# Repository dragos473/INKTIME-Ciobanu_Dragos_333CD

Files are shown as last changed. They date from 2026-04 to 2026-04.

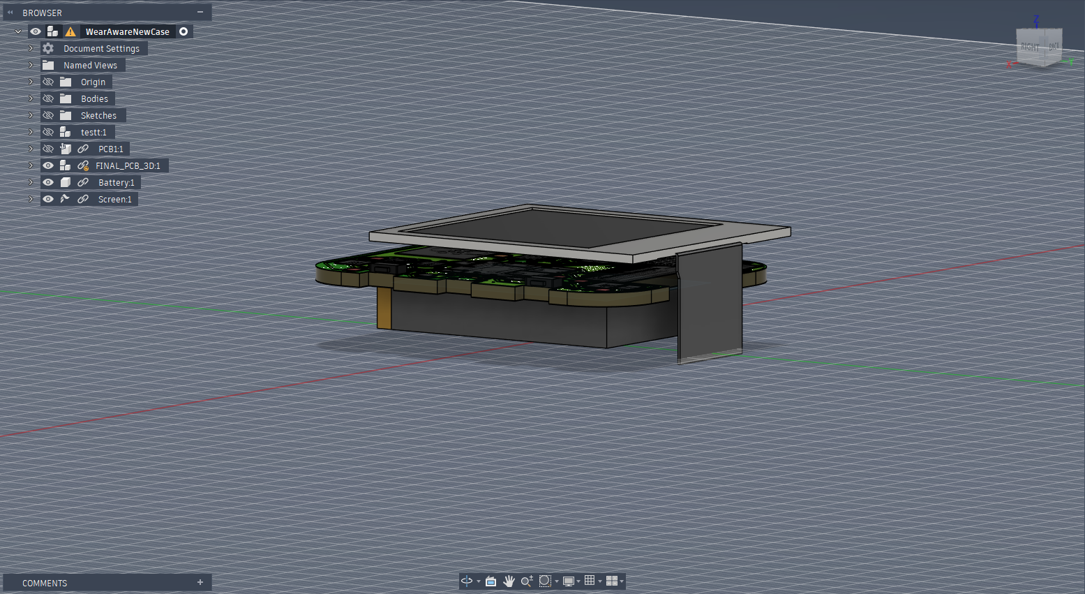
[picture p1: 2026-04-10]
Images/3Dmodel-noCase.PNG

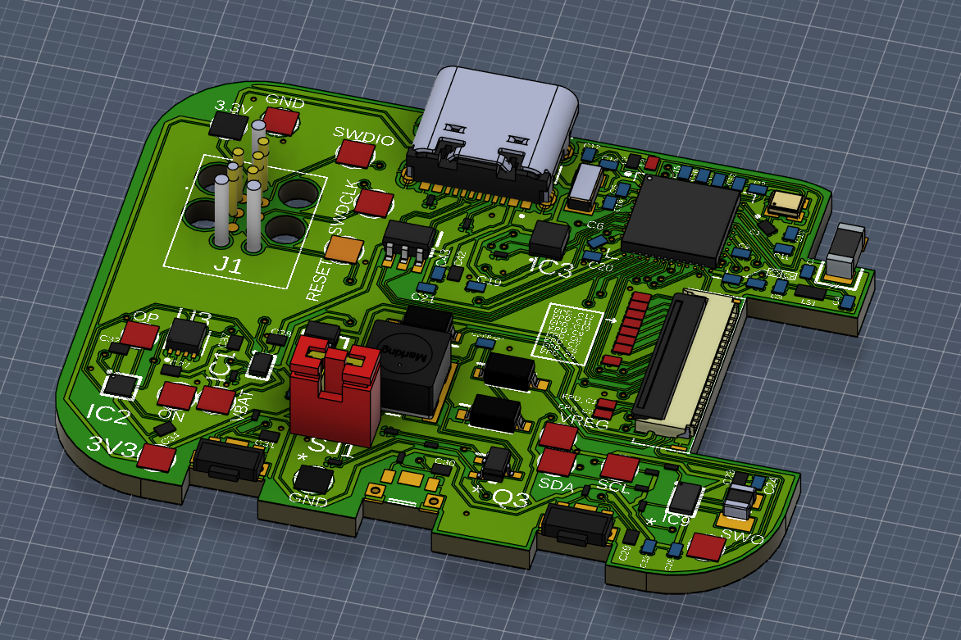
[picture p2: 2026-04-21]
Images/3DPCBTop.PNG

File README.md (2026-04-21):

# InkTime – Smartwatch Open Source

InkTime este un smartwatch open-source construit in jurul microcontroller-ului nRF52840. Are display e-paper de 1.54", feedback haptic, si incarcare prin USB-C.

## Diagrama Bloc

```
                         +-----------+
        USB-C ──VBUS──>──| BQ25180   |──VBAT──>──[ Baterie LiPo ]
        (J3)             | (Charger) |              |
          |              +-----------+               |
          |                   |                      |
          |                   v                      v
          |              +-----------+         +-----------+
          |              | RT6160A   |<──VREG──| MAX17048  |
          |              | (DC/DC)   |         | (Fuel     |
          |              +-----------+         |  Gauge)   |
          |                   |                +-----------+
          |                 3V3                      |
          |                   |                   ALERT
          v                   v                      |
     +--------------------------------------------+  |
     |               nRF52840                      |<-+
     |                                             |
     |   SPI ──> Display E-Paper (conector FPC J2) |
     |   I2C ──> BMA423 (IMU)                      |
     |   I2C ──> DRV2605 (Haptic Driver)           |
     |   I2C ──> BQ25180 / RT6160A / MAX17048      |
     |   GPIO ──> 3x Butoane (UP/ENTER/DOWN)       |
     |   USB ──> USB-C (D+/D-)                     |
     |   RF ──> Antena 2.4GHz (BLE)                |
     +---------------------------------------------+
```

## Descriere Hardware

### Microcontroller – nRF52840

nRF52840 e IC-ul principal al proiectului. E un SoC cu procesor Cortex-M4F, are 1MB flash si 256kB RAM si merge pana la 64MHz. Suporta BLE 5.0 si USB 2.0. Toate perifericele de pe placa comunica cu el prin I2C, SPI sau GPIO.

### Alimentare

Lantul de alimentare arata asa: USB-C (VBUS, 5V) → BQ25180 (incarcator LiPo) → baterie LiPo (VBAT) → RT6160A (convertor DC/DC buck-boost) → linia de 3V3.

### Display E-Paper

Display-ul se conecteaza printr-un conector FPC cu 24 de pini. Circuitul de drive pentru e-paper foloseste un boost converter ca sa genereze tensiunile mari (PREVGH si PREVGL) de care are nevoie panoul. Un P-MOSFET (DMG2305UX) controlat de pinul P1.01 porneste/opreste alimentarea circutului de display, ca sa poata fi oprit complet cand nu se face refresh.

Semnalele SPI (SCK, MOSI, CS) si GPIO-urile de control (DC, RST, BUSY) merg direct la nRF52840. Fiecare linie de tensiune mare are condensatoare de decuplare de 1µF/50V.

### IMU – BMA423

BMA423 e un accelerometru triaxial folosit pentru numararea pasilor si detectarea gesturilor. Comunica pe I2C. Pinul SDO e legat la GND printr-un rezistor de 0Ω (R3), ceea ce seteaza adresa I2C la 0x18. CSB e legat la VDD ca sa selecteze modul I2C. INT1 si INT2 merg la nRF52840 pentru interrupt-uri.

### Haptic Driver – DRV2605

DRV2605 controleaza un motor LRA/ERM pentru feedback haptic. E controlat prin I2C si activat prin GPIO (P0.12 → EN). Pinul IN/TRIG e legat la GND (nu se foloseste in modul I2C). OUT+ si OUT- se conecteaza la motor prin test pad-uri.

### USB-C si Protectie ESD

Conectorul USB-C (KH-TYPE-C-16P) furnizeaza alimentare (VBUS) si date (D+, D-). Doua rezistoare de 5.1kΩ pe CC1 si CC2 identifica dispozitivul ca UFP (sink). USBLC6-2SC6Y asigura protectie ESD pe liniile de date. D+/D- se conecteaza la controller-ul USB intern al nRF52840.

### Butoane

Trei butoane tactile (EVP-AKE31A): UP (P0.13), ENTER (P0.14), DOWN (P1.02). Fiecare buton are un pull-up de 10kΩ la 3V3 si un condensator de debounce de 1µF la GND. Cand e apasat, butonul trage pinul la GND (active-low).

### Debug SWD

Un footprint TC2030-IDC (tag-connect) ofera acces SWD (SWDIO, SWDCLK, RESET, VCC, GND). Pe placa sunt si test pad-uri pentru SWO, SWDIO, SWDCLK, RESET, 3V3 si GND.

### Magistrala I2C

Toate perifericele I2C sunt pe acelasi bus, pe pinii P0.06 (SDA) si P0.07 (SCL). Rezistoarele de pull-up sunt de 3.3kΩ, conectate la 3V3.

| Dispozitiv | Adresa I2C | Functie |
|---|---|---|
| BQ25180 | 0x6A | Incarcator baterie |
| RT6160A | 0x75 | Convertor DC/DC |
| MAX17048 | 0x36 | Fuel gauge |
| BMA423 | 0x18 | Accelerometru |
| DRV2605 | 0x5A | Driver haptic |

## Pinii nRF52840

| Pin | Pad | Semnal | Descriere |
|-----|-----|---|---|
| P0.00 | D2 | XL1 | Intrare cristal 32.768kHz |
| P0.01 | F2 | XL2 | Iesire cristal 32.768kHz |
| P0.02 | A12 | SCK | SPI clock catre display e-paper |
| P0.03 | B13 | MOSI | SPI data catre display e-paper |
| P0.05 | K2 | EPD_CS | SPI chip select pentru display |
| P0.06 | L1 | SDA | I2C data (bus comun) |
| P0.07 | M2 | SCL | I2C clock (bus comun) |
| P0.08 | N1 | IMU_INT1 | Interrupt 1 de la BMA423 |
| P0.10 | J24 | ALERT | Alerta baterie de la MAX17048 |
| P0.11 | T2 | PMIC_INT | Interrupt de la BQ25180 |
| P0.12 | U1 | HAPTIC_EN | Enable pentru DRV2605 |
| P0.13 | AD8 | BTN_UP | Buton UP (active-low) |
| P0.14 | AC9 | BTN_ENTER | Buton ENTER (active-low) |
| P0.15 | AD10 | EPD_DC | Data/Command pentru display |
| P0.16 | AC11 | EPD_RST | Reset display e-paper |
| P0.17 | AD12 | EPD_BUSY | Busy flag display e-paper |
| P0.18 | AC13 | RESET | Reset sistem |
| P1.00 | AD22 | SWO | Serial Wire Output (debug) |
| P1.01 | Y23 | PWR_EPD | Gate MOSFET alimentare display |
| P1.02 | W24 | BTN_DOWN | Buton DOWN (active-low) |
| P1.08 | P2 | IMU_INT2 | Interrupt 2 de la BMA423 |
| AD2 | — | VBUS | Detectie USB VBUS |
| AD4 | — | D- | USB data minus |
| AD6 | — | D+ | USB data plus |
| AA24 | — | SWDCLK | SWD clock (debug) |
| AC24 | — | SWDIO | SWD data (debug) |
| XC1/B24 | — | XC1 | Intrare cristal 32MHz |
| XC2/A23 | — | XC2 | Iesire cristal 32MHz |
| H23 | — | ANT | Iesire RF catre antena |
| W1, B1, A22, AD14, AD23 | — | VDD | Alimentare 3.3V |
| Y2 | — | VDDH | Alimentare 3.3V (high-voltage) |
| B7, F23 | — | VSS/GND | Masa |

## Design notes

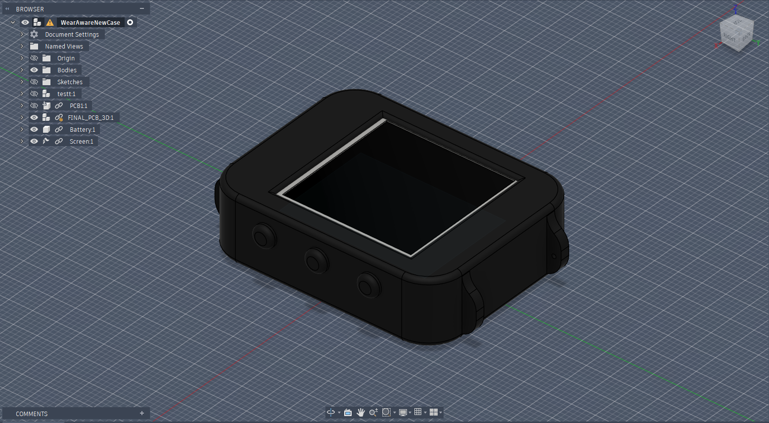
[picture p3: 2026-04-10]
Images/3Dmodel-withCase.PNG

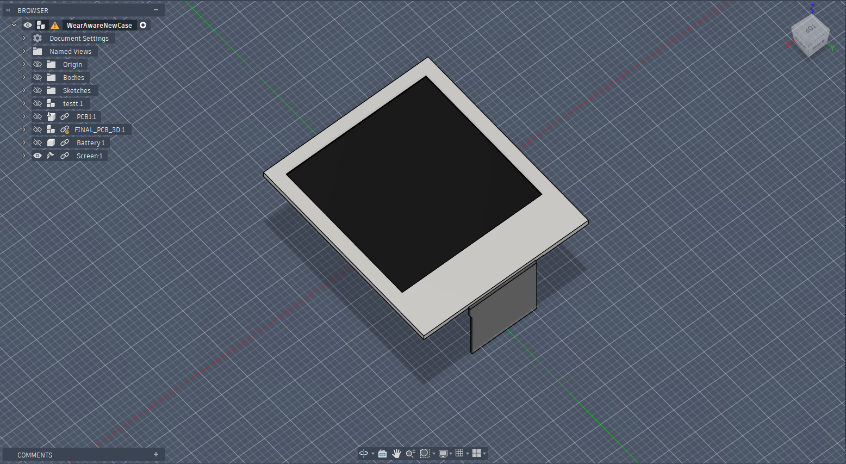
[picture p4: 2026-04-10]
Images/3DScreen.PNG

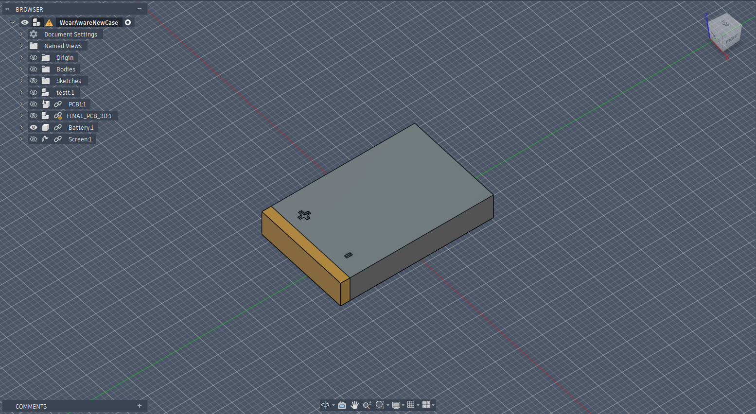
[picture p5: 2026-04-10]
Images/3DBattery.PNG

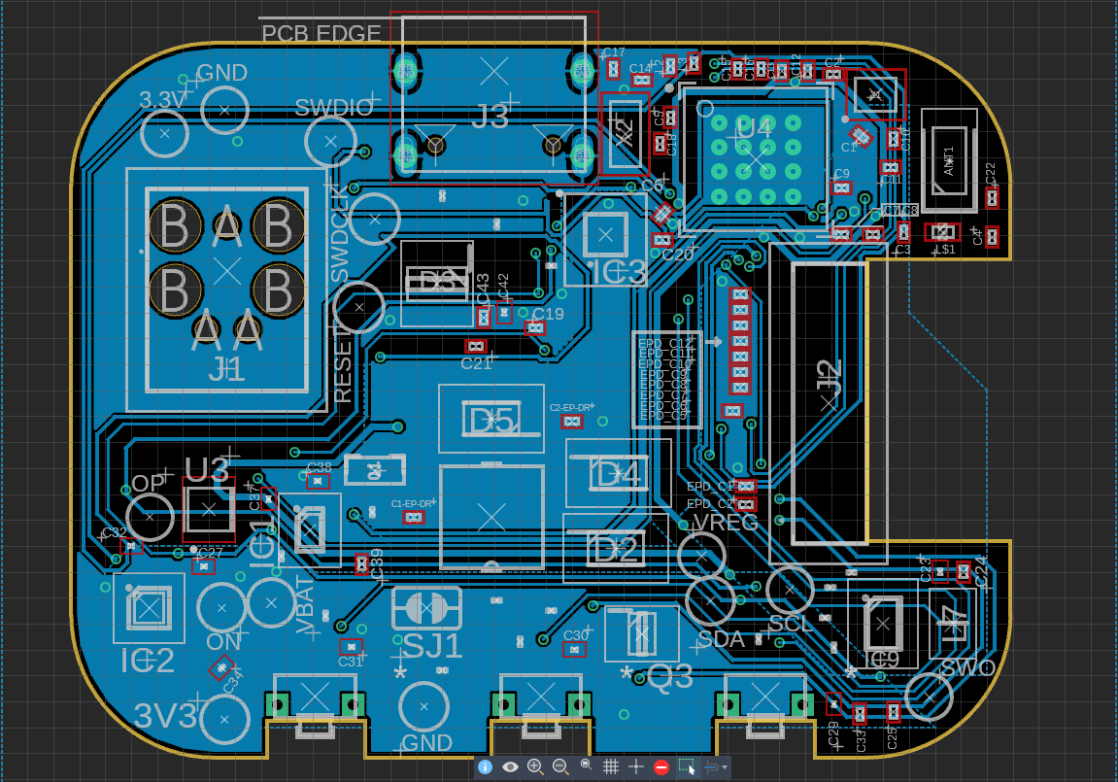
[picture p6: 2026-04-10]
Images/PCBBottom.PNG

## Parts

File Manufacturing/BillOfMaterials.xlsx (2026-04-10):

Reference Designators | Quantity | Description | Datasheet | Purchase Link | Package | Value | Manufacturer | Manufacturer Part Number | Vendor | Vendor Part Number | Top/Bottom
 | 1 | PCB Board |  |  | Board
3.3V, 3V3, GND, ON, OP, RESET, SCL, SDA, SWDCLK, SWDIO, SWO, TP_BAT_GND, VBAT, VREG | 14 | Test pad |  |  | HECTOR_WATCH_1_TP20R | HECTOR_WATCH_1_TPTP20R |  |  |  |  | Top
ANT1 | 1 | Antennas 2.45GHz ANTENNA | READ_DATASHEET | BUY_PART | 2450AT18B100E_ANTC3216X140N | 2450AT18B100E | Johanson Technology | 2450AT18B100E | LCSC | C2836414 | Top
C1, C2, C17, C18 | 4 | Generic chip capacitor | READ_DATASHEET | BUY_PART | NORDIC_NRF_3_RESC0201_L | 12pF | Murata | GRM0335C1H120JA01D | LCSC | C106295 | Top
C1-EP-DR, C24, C39 | 3 | Generic chip capacitor | READ_DATASHEET |  | NORDIC_NRF_3_RESC0201_L | 10uF | Murata | GRM155R60J106ME15 |  |  | Top
C2-EP-DR, C43 | 2 | Generic chip capacitor |  |  | NORDIC_NRF_3_RESC0201_L | 4.7uF |  |  |  |  | Top
C3, C4 | 2 | Generic chip capacitor |  |  | NORDIC_NRF_3_RESC0201_L | 1pF |  |  |  |  | Top
C5, C7, C12, C19 | 4 | Generic chip capacitor |  |  | NORDIC_NRF_3_RESC0201_L | 100nF | Murata | GRM033R60J104KE19D |  |  | Top
C6, C14, C20, C21 | 4 | Generic chip capacitor |  |  | NORDIC_NRF_3_RESC0201_L | 4.7μF |  |  |  |  | Top
C8 | 1 | Generic chip capacitor |  |  | NORDIC_NRF_3_RESC0201_L | 100nF N.C. |  |  |  |  | Top
C9 | 1 | Generic chip capacitor |  |  | NORDIC_NRF_3_RESC0201_L | 820pF |  |  |  |  | Top
C10, C13, C22 | 3 | Generic chip capacitor |  |  | NORDIC_NRF_3_RESC0201_L | N.C. |  |  |  |  | Top
C11 | 1 | Generic chip capacitor |  |  | NORDIC_NRF_3_RESC0201_L | 100pF |  |  |  |  | Top
C15 | 1 | Generic chip capacitor |  |  | NORDIC_NRF_3_RESC0201_L | 1.0μF |  |  |  |  | Top
C16 | 1 | Generic chip capacitor |  |  | NORDIC_NRF_3_RESC0201_L | 47nF |  |  |  |  | Top
C23, C27, C34, C42 | 4 | Check availability |  |  | CAPC0201X13N | 0.1uF |  |  |  |  | Top
C25, C33 | 2 | Generic chip capacitor |  |  | NORDIC_NRF_3_RESC0201_L | 22uF | Murata | GRM188R61A226ME15D |  |  | Top
C29, C30, C31, C32, C37, C38 | 6 | Check availability |  |  | CAPC0201X13N | 1uF |  |  |  |  | Top
D2, D4, D5 | 3 | ON SEMICONDUCTOR - MBR0530 - DIODE, SCHOTTKY, 0.5A, 30V, SOD-123 | READ_DATASHEET | BUY_PART | SOD3716X135N | MBR0530 | ON Semiconductor | MBR0530 | LCSC | C475718 | Top
D3 | 1 | Low Cap. ESD Protection Auto SOT-23-6 STMicroelectronics USBLC6-2SC6Y, Dual Uni-Directional TVS Diode Array, 6-Pin SOT-23 | READ_DATASHEET | BUY_PART | SOT95P280X145-6N | USBLC6-2SC6Y | STMicroelectronics | USBLC6-2SC6Y | LCSC | C323793 | Top
EPD_C1, EPD_C2, EPD_C6, EPD_C7, EPD_C8, EPD_C9, EPD_C10, EPD_C11, EPD_C12 | 9 | Generic chip capacitor |  |  | NORDIC_NRF_3_RESC0201_L | 1uF/50V |  |  |  |  | Top
EPD_C5 | 1 | Generic chip capacitor |  |  | NORDIC_NRF_3_RESC0201_L | 0.1uF/50V |  |  |  |  | Top
IC1 | 1 | Charger IC Lithium Ion/Polymer, Lithium Iron Phosphate 8-DSBGA (1.6x1.1) | READ_DATASHEET | BUY_PART | BQ25180YBGR_BGA8C40P2X4_100X155X50 | BQ25180YBGR | Texas Instruments | BQ25180YBGR | LCSC | C3682423 | Top
IC2 | 1 | Haptic Driver for ERM/LRA with Built-In Library and Smart Loop Architecture | READ_DATASHEET | BUY_PART | DRV2605YZFR_BGA9C50P3X3_144X144X62 | DRV2605YZFR | Texas Instruments | DRV2605YZFR | LCSC | C81079 | Top
IC3 | 1 | Accelerometers Triaxial low-g 12bit Acceleration Sensor | READ_DATASHEET | BUY_PART | BMA423_BMA423 | BMA423 | Bosch Sensortec | BMA423 | LCSC | C189517 | Top
IC9 | 1 | Buck-Boost Regulator Positive Output Step-Up/Step-Down I2C DC-DC Controller IC 15-WL-CSP (BSC) (1.4x2.3) | READ_DATASHEET | BUY_PART | RT6160AWSC_BGA15C40P3X5_140X230X60 | RT6160AWSC | Richtek | RT6160AWSC | LCSC | C3028302 | Top
J1 | 1 | CABLE ADAPTER 6 POS | READ_DATASHEET |  | TC2030-IDC_TC2030IDC | TC2030-IDC | Tag-Connect | TC2030-IDC |  |  | Top
J2 | 1 | FFC & FPC Connectors 0.5mm FPC RA SMT Dual Contact 24Ckt | READ_DATASHEET | BUY_PART | 503480-2400_5034802400 | 503480-2400 | Molex | 503480-2400 | LCSC | C234192 | Top
J3 | 1 | Check availability | READ_DATASHEET | BUY_PART | KINGHELM_KH-TYPE-C-16P | KH-TYPE-C-16P | Shenzhen Kinghelm | KH-TYPE-C-16P | LCSC | C709357 | Top
L$1 | 1 | Generic chip inductor |  |  | NORDIC_NRF_2_RESC0402_L | 3.9nH |  |  |  |  | Top
L1 | 1 |  |  |  | ESP32_C6_LIBRARY_2_IND_4828-WE-TPC_WRE | 68uH |  |  |  |  | Top
L2 | 1 | Generic chip inductor |  |  | NORDIC_NRF_2_RESC0201_L | 10μH |  |  |  |  | Top
L3 | 1 | Generic chip inductor |  |  | NORDIC_NRF_2_RESC0201_L | 15nH |  |  |  |  | Top
L7 | 1 | SMD / SMT Inductors (Coils), L=0.47?H, L x W x T : |  | BUY_PART | MLP2016SR47MT0S1_INDC2016X100N | FTC252012SR47MBCA | Changjiang | FTC252012SR47MBCA | LCSC | C5832368 | Top
Q1 | 1 | P-channel MOSFETs | READ_DATASHEET | BUY_PART | ESP32_WROVER_SPARKFUN-DISCRETESEMI_SOT23-3 | 20V/4.2A/52mΩ/1.4W | AOS | AO3401A | LCSC | C15127 | Top
Q3 | 1 | MOSFET N-Ch 30V 1.5A TrenchFET SC70 Vishay Si1308EDL-T1-GE3 N-channel MOSFET Transistor, 1.5 A, 30 V, 3-Pin SC-70 | READ_DATASHEET | BUY_PART | SOT65P210X110-3N | SI1308EDL-T1-GE3 | Vishay Siliconix | SI1308EDL-T1-GE3 | LCSC | C7603347 | Top
R_PWR_EPD | 1 | 7.68k 0201 Thin Film Surface Mount Fixed Resistor +/-0.5% 0.031W CPF0201D7K68C1 | READ_DATASHEET | BUY_PART | R0201 | 10k | YAGEO | RC0201FR-0710KL | LCSC | C106225 | Top
R_TYPE_SEL | 1 | 7.68k 0201 Thin Film Surface Mount Fixed Resistor +/-0.5% 0.031W CPF0201D7K68C1 |  |  | R0201 | 2.2 |  |  |  |  | Top
R1_EP_DR' | 1 | 7.68k 0201 Thin Film Surface Mount Fixed Resistor +/-0.5% 0.031W CPF0201D7K68C1 |  |  | R0201 | 0.47 |  |  |  |  | Top
R1_USB, R2_USB | 2 | 7.68k 0201 Thin Film Surface Mount Fixed Resistor +/-0.5% 0.031W CPF0201D7K68C1 |  |  | R0201 | 5K1 |  |  |  |  | Top
R2, R3, R4 | 3 | 7.68k 0201 Thin Film Surface Mount Fixed Resistor +/-0.5% 0.031W CPF0201D7K68C1 |  |  | R0201 | 0 |  |  |  |  | Top
R2_EP_DR, R5, R7, R8 | 4 | 7.68k 0201 Thin Film Surface Mount Fixed Resistor +/-0.5% 0.031W CPF0201D7K68C1 | READ_DATASHEET | BUY_PART | R0201 | 10K | YAGEO | RC0201FR-0710KL | LCSC | C106225 | Top
R9 | 1 | 7.68k 0201 Thin Film Surface Mount Fixed Resistor +/-0.5% 0.031W CPF0201D7K68C1 | READ_DATASHEET | BUY_PART | CPF0201D7K68C1_0201 | 10k | YAGEO | RC0201FR-0710KL | LCSC | C106225 | Top
R17, R18 | 2 | 7.68k 0201 Thin Film Surface Mount Fixed Resistor +/-0.5% 0.031W CPF0201D7K68C1 |  |  | R0201 | 3K3 |  |  |  |  | Top
SJ1 | 1 | SMD solder JUMPER |  |  | JUMPER_SJ |  |  |  |  |  | Top
SW_DN, SW_ENT, SW_UP | 3 |  | READ_DATASHEET | BUY_PART | SW_EVP-AKE31A_PAN | 2025-10-22_07-23-44_LIBRARY_EVP-AKE31ASW_EVP-AKE31A_PAN | Panasonic | EVP-AKE31A | LCSC | C22333 | Top
U3 | 1 | Check availability | READ_DATASHEET | BUY_PART | SON50P200X200X80-9N | MAX17048G+T10 | Maxim Integrated | MAX17048G+T10 | LCSC | C2682616 | Top
U4 | 1 | nRF52840 | READ_DATASHEET | BUY_PART | NORDIC_NRF_4_AQFN50P700X700X85_HS-74N | NRF52840_QF | Nordic Semiconductor | NRF52840-QIAA-R | LCSC | C190794 | Top
X1 | 1 |  | READ_DATASHEET | BUY_PART | NORDIC_NRF_BT-XTAL_2016_N | 32MHz | NDK | NT2016SA / NX2016SA | LCSC | C383840 | Top
X2 | 1 |  | READ_DATASHEET | BUY_PART | NORDIC_NRF_1_XTAL_3215_N | 32.768kHz | NDK | NX3215SA | LCSC | C7462225 | Top

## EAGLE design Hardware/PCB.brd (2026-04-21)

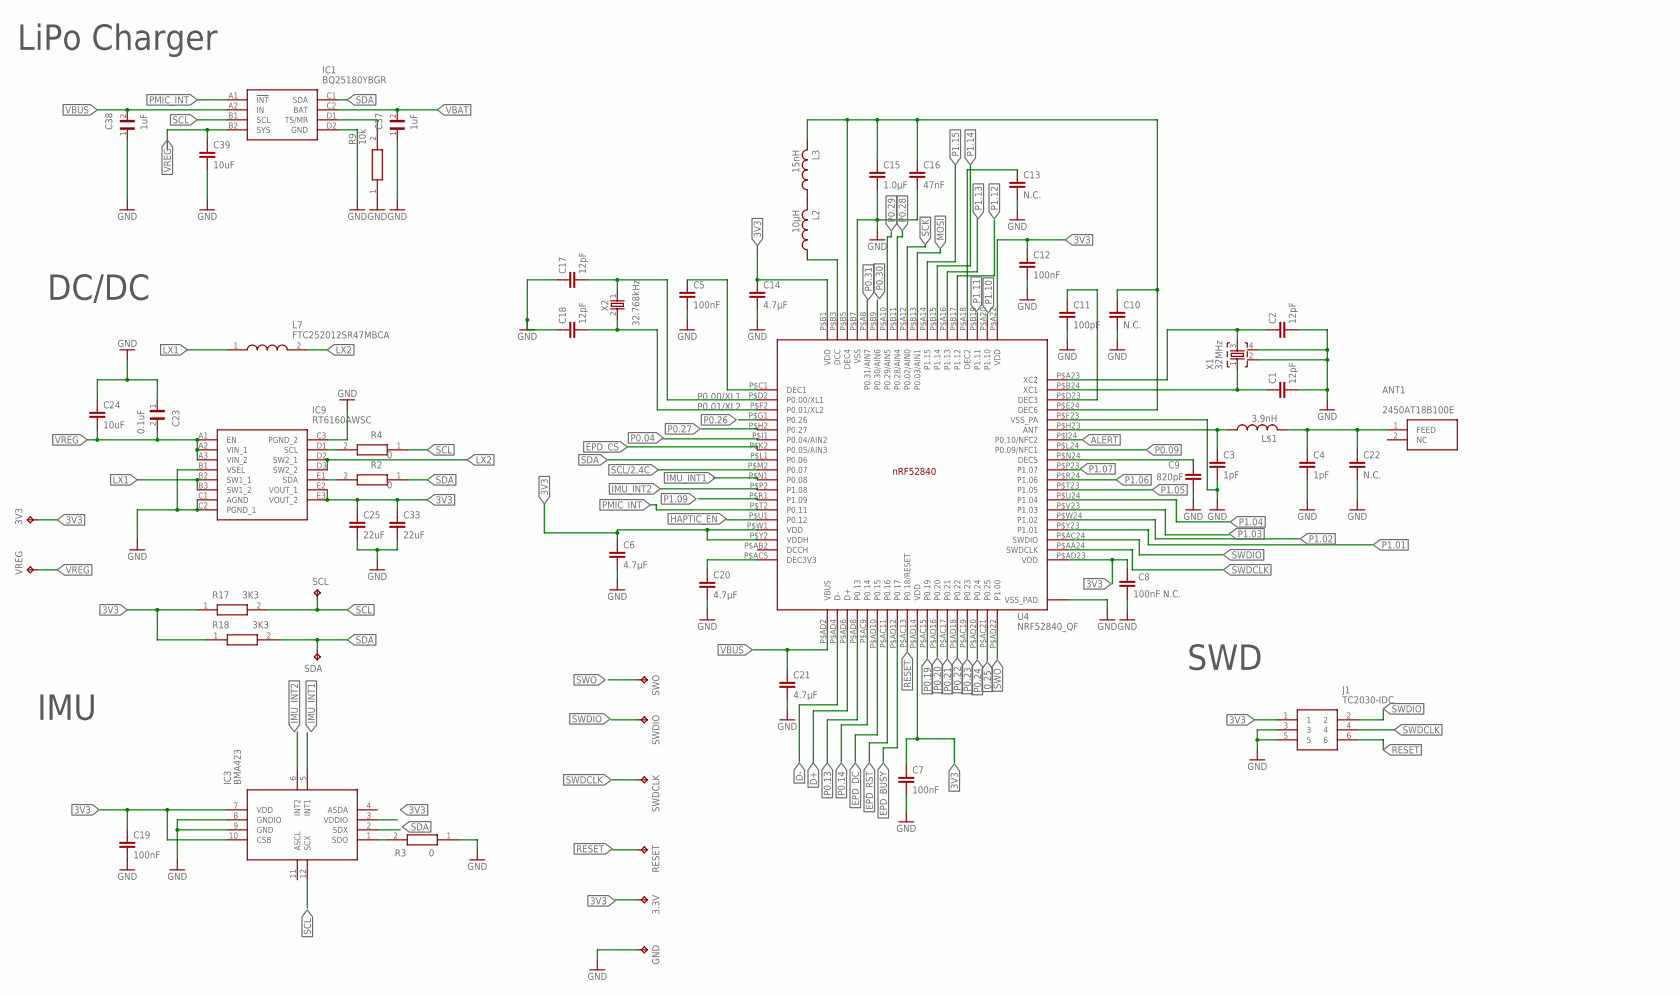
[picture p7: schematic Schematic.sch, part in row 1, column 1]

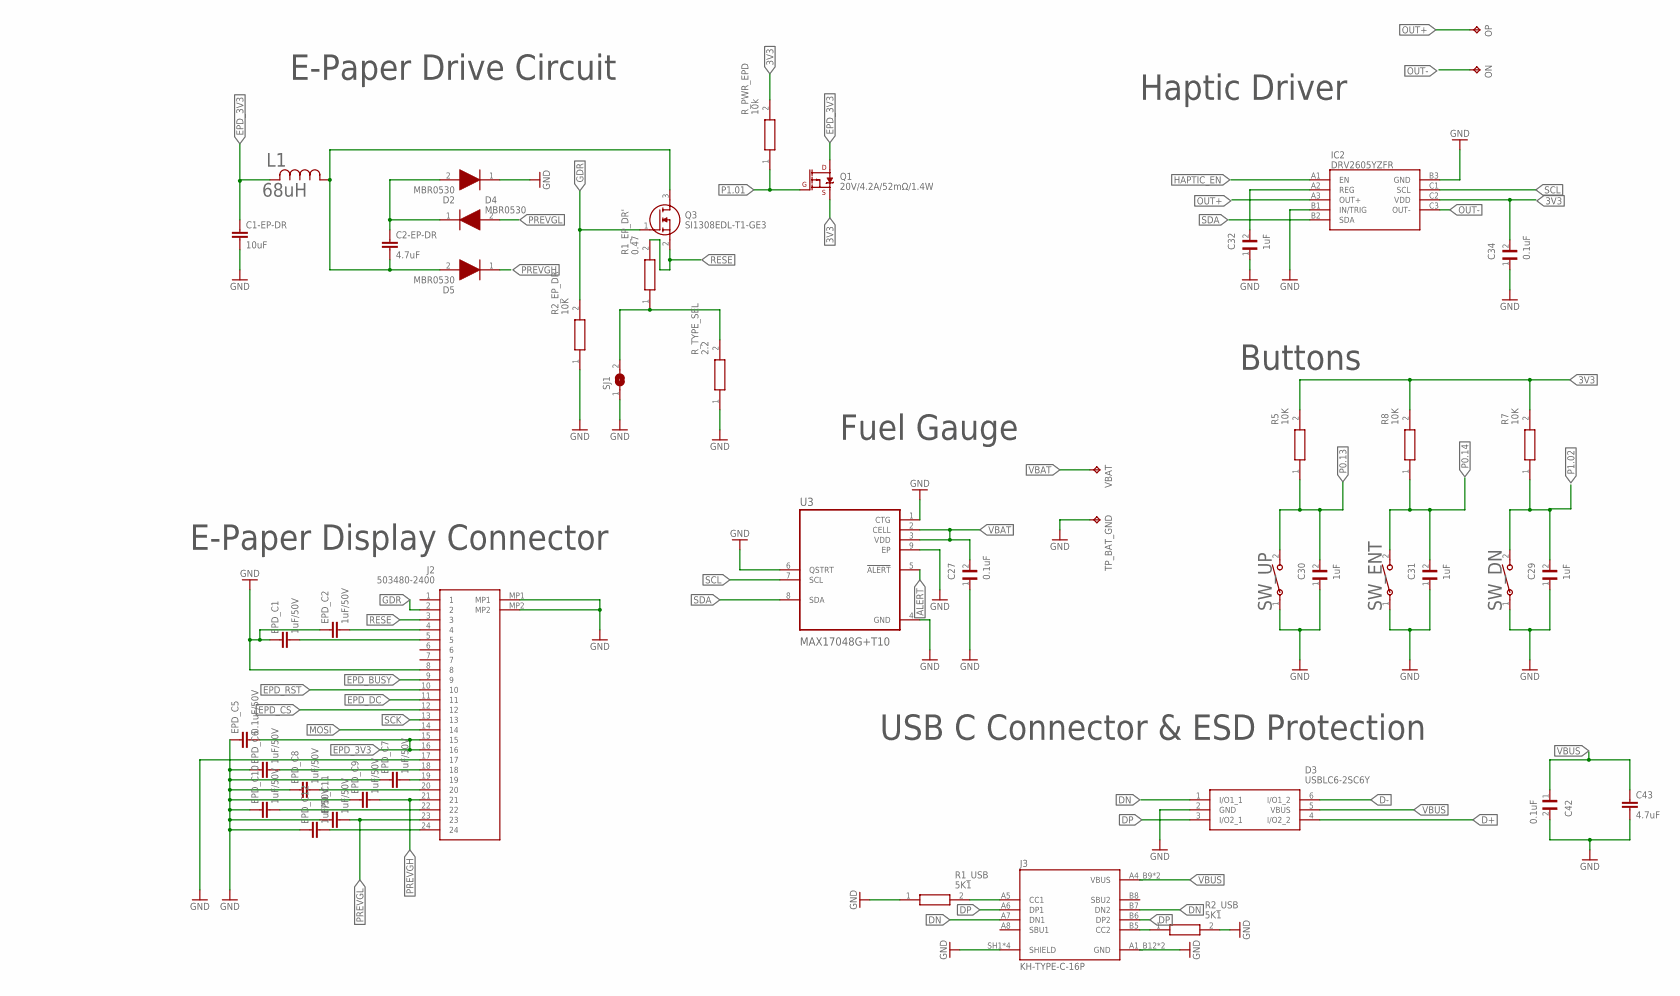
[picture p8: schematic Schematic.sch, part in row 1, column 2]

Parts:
3.3V, 3V3: HECTOR_WATCH_1_TPTP20R; HECTOR_WATCH_1_TP20R
ANT1: 2450AT18B100E; 2450AT18B100E_ANTC3216X140N
C1, C2, C17, C18: 12pF; NORDIC_NRF_3_RESC0201_L
C1-EP-DR, C24, C39: 10uF; NORDIC_NRF_3_RESC0201_L
C2-EP-DR, C43: 4.7uF; NORDIC_NRF_3_RESC0201_L
C3, C4: 1pF; NORDIC_NRF_3_RESC0201_L
C5, C7, C12, C19: 100nF; NORDIC_NRF_3_RESC0201_L
C6, C14, C20, C21: 4.7μF; NORDIC_NRF_3_RESC0201_L
C8: 100nF N.C.; NORDIC_NRF_3_RESC0201_L
C9: 820pF; NORDIC_NRF_3_RESC0201_L
C10, C13, C22: N.C.; NORDIC_NRF_3_RESC0201_L
C11: 100pF; NORDIC_NRF_3_RESC0201_L
C15: 1.0μF; NORDIC_NRF_3_RESC0201_L
C16: 47nF; NORDIC_NRF_3_RESC0201_L
C23, C27, C34, C42: 0.1uF; GRM011R60J152KE01L_2_CAPC0201X13N
C25, C33: 22uF; NORDIC_NRF_3_RESC0201_L
C29, C30, C31, C32, C37, C38: 1uF; GRM011R60J152KE01L_2_CAPC0201X13N
D2, D4, D5: MBR0530; ESP32_C6_LIBRARY_5_SOD3716X135N
D3: USBLC6-2SC6Y; ESP32_C6_LIBRARY_3_SOT95P280X145-6N
EPD_C1, EPD_C2, EPD_C6, EPD_C7, EPD_C8, EPD_C9, EPD_C10, EPD_C11, EPD_C12: 1uF/50V; NORDIC_NRF_3_RESC0201_L
EPD_C5: 0.1uF/50V; NORDIC_NRF_3_RESC0201_L
GND: HECTOR_WATCH_1_TPTP20R; HECTOR_WATCH_1_TP20R
IC1: BQ25180YBGR; BQ25180YBGR_BGA8C40P2X4_100X155X50
IC2: DRV2605YZFR; DRV2605YZFR_BGA9C50P3X3_144X144X62
IC3: BMA423; BMA423_BMA423
IC9: RT6160AWSC; RT6160AWSC_BGA15C40P3X5_140X230X60
J1: TC2030-IDC; TC2030-IDC_TC2030IDC
J2: 503480-2400; 503480-2400_5034802400
J3: KH-TYPE-C-16P; KH-TYPE-C-16P_KINGHELM_KH-TYPE-C-16P
L1: 68uH; ESP32_C6_LIBRARY_2_IND_4828-WE-TPC_WRE
L2: 10μH; NORDIC_NRF_2_RESC0201_L
L3: 15nH; NORDIC_NRF_2_RESC0201_L
L7: FTC252012SR47MBCA; MLP2016SR47MT0S1_INDC2016X100N
L$1: 3.9nH; NORDIC_NRF_2_RESC0402_L
ON: HECTOR_WATCH_1_TPTP20R; HECTOR_WATCH_1_TP20R
OP: HECTOR_WATCH_1_TPTP20R; HECTOR_WATCH_1_TP20R
Q1: 20V/4.2A/52mΩ/1.4W; ESP32_C6_LIBRARY_4_ESP32_C6_LIBRARY_4_ESP32_C6_LIBRARY_4_ES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
Q3: SI1308EDL-T1-GE3; ESP32_C6_LIBRARY_6_SOT65P210X110-3N
R1_EP_DR': 0.47; ERA-1AEB3401C_0201
R1_USB, R2_USB: 5K1; ERA-1AEB3401C_0201
R2, R3, R4: 0; ERA-1AEB3401C_0201
R2_EP_DR, R5, R7, R8: 10K; ERA-1AEB3401C_0201
R9: 10k; CPF0201D7K68C1_0201
R17, R18: 3K3; ERA-1AEB3401C_0201
RESET: HECTOR_WATCH_1_TPTP20R; HECTOR_WATCH_1_TP20R
R_PWR_EPD: 10k; ERA-1AEB3401C_0201
R_TYPE_SEL: 2.2; ERA-1AEB3401C_0201
SCL: HECTOR_WATCH_1_TPTP20R; HECTOR_WATCH_1_TP20R
SDA: HECTOR_WATCH_1_TPTP20R; HECTOR_WATCH_1_TP20R
SJ1: ESP32_C6_LIBRARY_7_JUMPER_SJ
SWDCLK: HECTOR_WATCH_1_TPTP20R; HECTOR_WATCH_1_TP20R
SWDIO: HECTOR_WATCH_1_TPTP20R; HECTOR_WATCH_1_TP20R
SWO: HECTOR_WATCH_1_TPTP20R; HECTOR_WATCH_1_TP20R
SW_DN: 2025-10-22_07-23-44_LIBRARY_EVP-AKE31ASW_EVP-AKE3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; 2025-10-22_07-23-44_LIBRARY_SW_EVP-AKE31A_PAN
SW_ENT: 2025-10-22_07-23-44_LIBRARY_EVP-AKE31ASW_EVP-AKE3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; 2025-10-22_07-23-44_LIBRARY_SW_EVP-AKE31A_PAN
SW_UP: 2025-10-22_07-23-44_LIBRARY_EVP-AKE31ASW_EVP-AKE3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; 2025-10-22_07-23-44_LIBRARY_SW_EVP-AKE31A_PAN
TP_BAT_GND: HECTOR_WATCH_1_TPTP20R; HECTOR_WATCH_1_TP20R
U3: MAX17048G+T10; ESP32_C6_LIBRARY_SON50P200X200X80-9N
U4: NRF52840_QF; NORDIC_NRF_4_AQFN50P700X700X85_HS-74N
VBAT: HECTOR_WATCH_1_TPTP20R; HECTOR_WATCH_1_TP20R
VREG: HECTOR_WATCH_1_TPTP20R; HECTOR_WATCH_1_TP20R
X1: 32MHz; NORDIC_NRF_BT-XTAL_2016_N
X2: 32.768kHz; NORDIC_NRF_1_XTAL_3215_N

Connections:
0.25: U4.P$AC21 (P0.25)
3V3: 3.3V.TP, 3V3.TP, C6.1, C7.1, C8.1, C12.1, C14.1, C19.1, C25.1, C33.1, C34.2, IC2.C2 (VDD), IC3.3 (VDDIO), IC3.7 (VDD), IC3.10 (CSB), IC9.E2 (VOUT_1), IC9.E3 (VOUT_2), J1.1, Q1.2 (S), R5.2, R7.2, R8.2, R17.1, R18.1, R_PWR_EPD.2, U4.P$A22 (VDD), U4.P$AD14 (VDD), U4.P$AD23 (VDD), U4.P$B1 (VDD), U4.P$W1 (VDD), U4.P$Y2 (VDDH)
ALERT: U3.5 (!ALERT), U4.P$J24 (P0.10/NFC2)
D+: D3.4 (I/O2_2), U4.P$AD6 (D+)
D-: D3.6 (I/O1_2), U4.P$AD4 (D-)
DN: D3.1 (I/O1_1), J3.A7 (DN1), J3.B7 (DN2)
DP: D3.3 (I/O2_1), J3.A6 (DP1), J3.B6 (DP2)
EPD_3V3: C1-EP-DR.1, EPD_C5.2, J2.15, J2.16, L1.2, Q1.3 (D)
EPD_BUSY: J2.9, U4.P$AD12 (P0.17)
EPD_CS: J2.12, U4.P$K2 (P0.05/AIN3)
EPD_DC: J2.11, U4.P$AD10 (P0.15)
EPD_RST: J2.10, U4.P$AC11 (P0.16)
GDR: J2.2, Q3.1 (G), R2_EP_DR.2
GND: C1.2, C1-EP-DR.2, C2.2, C3.2, C4.2, C5.2, C6.2, C7.2, C8.2, C9.2, C10.2, C11.2, C12.2, C13.2, C14.2, C15.2, C16.2, C17.1, C18.1, C19.2, C20.2, C21.2, C22.2, C23.1, C24.1, C25.2, C27.1, C29.1, C30.1, C31.1, C32.1, C33.2, C34.1, C37.1, C38.1, C39.2, C42.2, C43.2, D2.1 (K), D3.2 (GND), EPD_C1.1, EPD_C2.1, EPD_C5.1, EPD_C6.1, EPD_C7.1, EPD_C8.1, EPD_C9.1, EPD_C10.1, EPD_C11.1, EPD_C12.1, GND.TP, IC1.D2 (GND), IC2.B1 (IN/TRIG), IC2.B3 (GND), IC3.8 (GNDIO), IC3.9 (GND), IC9.B1 (VSEL), IC9.C1 (AGND), IC9.C2 (PGND_1), IC9.C3 (PGND_2), J1.3, J1.5, J2.8, J2.17, J2.MP1, J2.MP2, J3.A1_B12 (GND), J3.A12_B1 (GND), J3.SH1 (SHIELD), J3.SH2 (SHIELD), J3.SH3 (SHIELD), J3.SH4 (SHIELD), R1_USB.1, R2_EP_DR.1, R2_USB.2, R3.1, R9.1, R_TYPE_SEL.1, SJ1.1, SW_DN.1, SW_ENT.1, SW_UP.1, TP_BAT_GND.TP, U3.1 (CTG), U3.4 (GND), U3.6 (QSTRT), U3.9 (EP), U4.P$74 (VSS_PAD), U4.P$75 (VSS_PAD), U4.P$76 (VSS_PAD), U4.P$77 (VSS_PAD), U4.P$78 (VSS_PAD), U4.P$79 (VSS_PAD), U4.P$80 (VSS_PAD), U4.P$81 (VSS_PAD), U4.P$82 (VSS_PAD), U4.P$83 (VSS_PAD), U4.P$84 (VSS_PAD), U4.P$85 (VSS_PAD), U4.P$86 (VSS_PAD), U4.P$87 (VSS_PAD), U4.P$88 (VSS_PAD), U4.P$89 (VSS_PAD), U4.P$90 (VSS_PAD), U4.P$B7 (VSS), U4.P$F23 (VSS_PA), X1.2, X1.4
HAPTIC_EN: IC2.A1 (EN), U4.P$U1 (P0.12)
IMU_INT1: IC3.5 (INT1), U4.P$N1 (P0.08)
IMU_INT2: IC3.6 (INT2), U4.P$P2 (P1.08)
LX1: IC9.B2 (SW1_1), IC9.B3 (SW1_2), L7.1
LX2: IC9.D2 (SW2_1), IC9.D3 (SW2_2), L7.2
MOSI: J2.14, U4.P$B13 (P0.03/AIN1)
unnamed: IC1.D1 (TS/MR), R9.2
unnamed: IC9.D1 (SCL), R4.2
unnamed: IC9.E1 (SDA), R2.2
unnamed: C5.1, U4.P$C1 (DEC1)
unnamed: C20.1, U4.P$AC5 (DEC3V3)
unnamed: C9.1, U4.P$N24 (DEC5)
unnamed: C3.1, L$1.1, U4.P$H23 (ANT)
unnamed: ANT1.1 (FEED), C4.1, C22.1, L$1.2
unnamed: C2.1, U4.P$A23 (XC2), X1.3
unnamed: C1.1, U4.P$B24 (XC1), X1.1
unnamed: C10.1, C15.1, C16.1, L3.2, U4.P$B5 (DEC4), U4.P$E24 (DEC6)
unnamed: C11.1, U4.P$D23 (DEC3)
unnamed: C13.1, U4.P$A18 (DEC2)
unnamed: L2.2, L3.1
unnamed: L2.1, U4.P$B3 (DCC)
unnamed: IC3.1 (SDO), R3.2
unnamed: C2-EP-DR.2, D5.2 (A), L1.1, Q3.3 (D)
unnamed: C2-EP-DR.1, D2.2 (A), D4.1 (K)
unnamed: R1_EP_DR'.1, R_TYPE_SEL.2, SJ1.2
unnamed: C32.2, IC2.A2 (REG)
unnamed: EPD_C2.2, J2.4
unnamed: EPD_C1.2, J2.5
unnamed: EPD_C6.2, J2.18
unnamed: EPD_C7.2, J2.19
unnamed: EPD_C8.2, J2.20
unnamed: EPD_C10.2, J2.22
unnamed: EPD_C12.2, J2.24
unnamed: J3.B5 (CC2), R2_USB.1
unnamed: J3.A5 (CC1), R1_USB.2
OUT+: IC2.A3 (OUT+), OP.TP
OUT-: IC2.C3 (OUT-), ON.TP
P0.00/XL1: C17.2, U4.P$D2 (P0.00/XL1), X2.1
P0.01/XL2: C18.2, U4.P$F2 (P0.01/XL2), X2.2
P0.04: U4.P$J1 (P0.04/AIN2)
P0.09: U4.P$L24 (P0.09/NFC1)
P0.13: C30.2, R5.1, SW_UP.2, U4.P$AD8 (P0.13)
P0.14: C31.2, R8.1, SW_ENT.2, U4.P$AC9 (P0.14)
P0.19: U4.P$AC15 (P0.19)
P0.20: U4.P$AD16 (P0.20)
P0.21: U4.P$AC17 (P0.21)
P0.22: U4.P$AD18 (P0.22)
P0.23: U4.P$AC19 (P0.23)
P0.24: U4.P$AD20 (P0.24)
P0.26: U4.P$G1 (P0.26)
P0.27: U4.P$H2 (P0.27)
P0.28: U4.P$B11 (P0.28/AIN4)
P0.29: U4.P$A10 (P0.29/AIN5)
P0.30: U4.P$B9 (P0.30/AIN6)
P0.31: U4.P$A8 (P0.31/AIN7)
P1.01: Q1.1 (G), R_PWR_EPD.1, U4.P$Y23 (P1.01)
P1.02: C29.2, R7.1, SW_DN.2, U4.P$W24 (P1.02)
P1.03: U4.P$V23 (P1.03)
P1.04: U4.P$U24 (P1.04)
P1.05: U4.P$T23 (P1.05)
P1.06: U4.P$R24 (P1.06)
P1.07: U4.P$P23 (P1.07)
P1.09: U4.P$R1 (P1.09)
P1.10: U4.P$A20 (P1.10)
P1.11: U4.P$B19 (P1.11)
P1.12: U4.P$B17 (P1.12)
P1.13: U4.P$A16 (P1.13)
P1.14: U4.P$B15 (P1.14)
P1.15: U4.P$A14 (P1.15)
PMIC_INT: IC1.A1 (!INT), U4.P$T2 (P0.11)
PREVGH: D5.1 (K), EPD_C9.2, J2.21
PREVGL: D4.2 (A), EPD_C11.2, J2.23
RESE: J2.3, Q3.2 (S), R1_EP_DR'.2
RESET: J1.6, RESET.TP, U4.P$AC13 (P0.18/RESET)
SCK: J2.13, U4.P$A12 (P0.02/AIN0)
SCL: IC1.B1 (SCL), IC2.C1 (SCL), IC3.12 (SCX), R4.1, R17.2, SCL.TP, U3.7 (SCL)
SCL/2.4C: U4.P$M2 (P0.07)
SDA: IC1.C1 (SDA), IC2.B2 (SDA), IC3.2 (SDX), R2.1, R18.2, SDA.TP, U3.8 (SDA), U4.P$L1 (P0.06)
SWDCLK: J1.4, SWDCLK.TP, U4.P$AA24 (SWDCLK)
SWDIO: J1.2, SWDIO.TP, U4.P$AC24 (SWDIO)
SWO: SWO.TP, U4.P$AD22 (P1.00)
VBAT: C27.2, C37.2, IC1.C2 (BAT), U3.2 (CELL), U3.3 (VDD), VBAT.TP
VBUS: C21.1, C38.2, C42.1, C43.1, D3.5 (VBUS), IC1.A2 (IN), J3.A4_B9 (VBUS), J3.A9_B4 (VBUS), U4.P$AD2 (VBUS)
VREG: C23.2, C24.2, C39.1, IC1.B2 (SYS), IC9.A1 (EN), IC9.A2 (VIN_1), IC9.A3 (VIN_2), VREG.TP

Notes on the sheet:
LiPo Charger
DC/DC
IMU
SWD
E-Paper Drive Circuit
E-Paper Display Connector
Fuel Gauge
Haptic Driver
Buttons
USB C Connector & ESD Protection

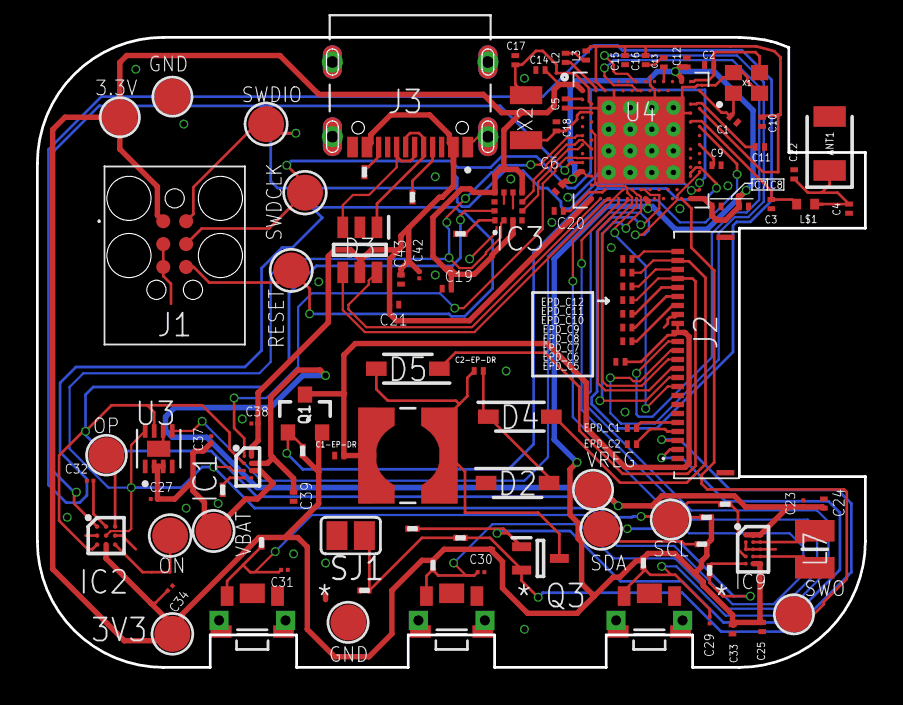
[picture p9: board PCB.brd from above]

Board: 2 copper layers, 46.0 x 35.0 mm, 105 parts (0 on the bottom side), 70 nets.

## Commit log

2026-04-10 project files uploaded
    [PCB.brd, Schematic.sch]
2026-04-21 resolved all issues
    [PCB.brd, Schematic.sch]

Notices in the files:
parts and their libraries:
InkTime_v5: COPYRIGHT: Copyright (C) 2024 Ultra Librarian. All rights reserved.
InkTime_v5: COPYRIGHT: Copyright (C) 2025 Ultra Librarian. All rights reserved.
